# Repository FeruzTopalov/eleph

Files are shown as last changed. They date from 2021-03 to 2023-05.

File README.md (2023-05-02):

# **ELEPH** - _Never Get Lost!_

> **Note**
> Development of this device has been finished, only bug-fixes in the FW are possible
> There is an improved version of this device being under development, please see <https://github.com/FeruzTopalov/spoke>

<p align="center">
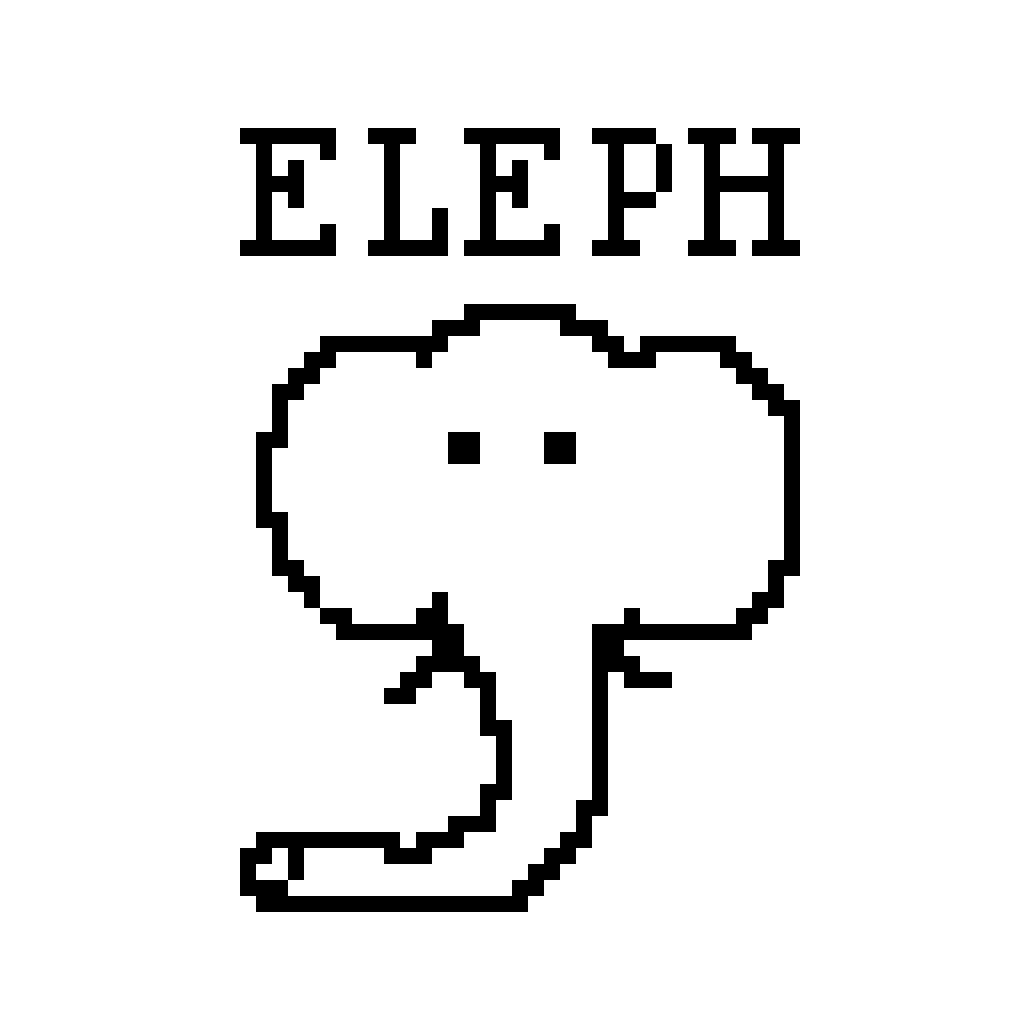
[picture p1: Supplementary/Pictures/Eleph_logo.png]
  
</p>

<p align="center">
  <i>Dedicated to my friend Alexander Sadaev, rock climber.</i>
</p>

Eleph is a GPS-based Local Relative Navigation System (LRNS) for group of up to 6 members. It allows you to share your positional data in **real-time** among other Eleph-devices and navigate to each of them in a relative manner by providing **Distance** and **Azimuth** information - like RADAR does.

## Demonstration

Before diving into the details, watch the demo on **YouTube**: <https://youtu.be/EMacKdg9Z_0>

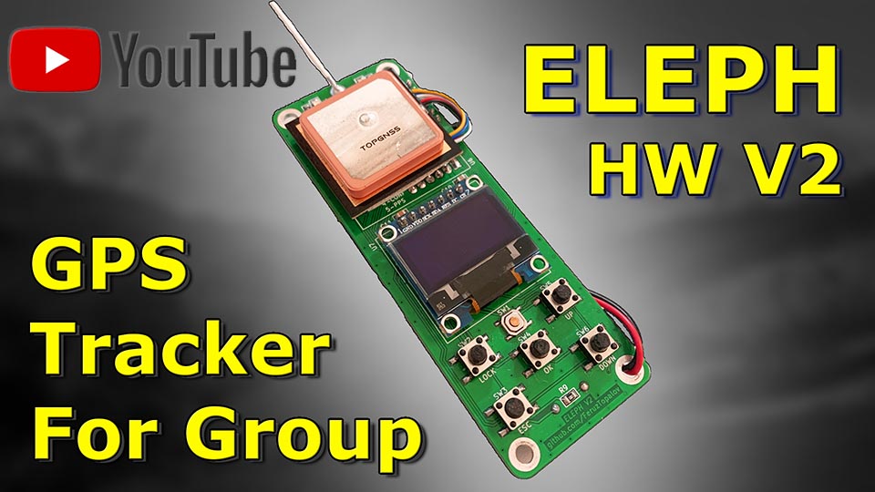
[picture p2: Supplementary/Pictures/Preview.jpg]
YouTube Video!


## Problem & Solution

As long as you stay under cell-coverage a navigation, either absolute or relative, is not a problem at all. You just use your phone with maps and messengers to find or share locations. Things change when you go off-grid. Hiking, skiing, sailing or whatever outdoor activity are a potential place to lose sight of your teammates. How to navigate in the group? Hopefully, there are couple of solutions available on the market:

* [LynQ](https://lynqme.com/pages/dev-consumer)
* [XQUAD](https://www.indiegogo.com/projects/xquad-smart-location-tracking-without-phones#/)
* [GoFindMe](https://www.indiegogo.com/projects/gofindme-a-gps-tracker-works-without-cell-service/#/)
* [GoTenna](https://gotennamesh.com/products/mesh)
* Also [GARMIN Dog collar](https://buy.garmin.com/en-US/US/c12522-p1.html)
* Also any [AIS](https://en.wikipedia.org/wiki/Automatic_identification_system) system

unfortunately all of them are commercial. But not the **Eleph**! 

**Eleph** is _open-source/open-hardware_ device which contains all major features needed for group navigation, such as:

* Detailed absolute positional information about each device in group
* RADAR-like interface with relative positional information about each device in group
* Memory slots to hold the position of any device and navigate it later
* GeoFence feature
* Timeout feature
* Alarm button

Due to open-source and simple and cheap hardware, Eleph is highly flexible solution that could be adapted to any use case you want:

* Hiking
* Climbing
* Sailing
* Hunting with the dogs
* Assets tracking
* and more...

## Technology

Eleph is written in pure C and runs on STM32 microcontroller. It has GPS module to receive positional data and synchronization signal, radio transceiver to exchange with radio packets between other devices, graphical display to show information on it, EEPROM memory IC to store coordinates, tactile buttons to control the device, buzzer to notify about events and couple of LEDs.

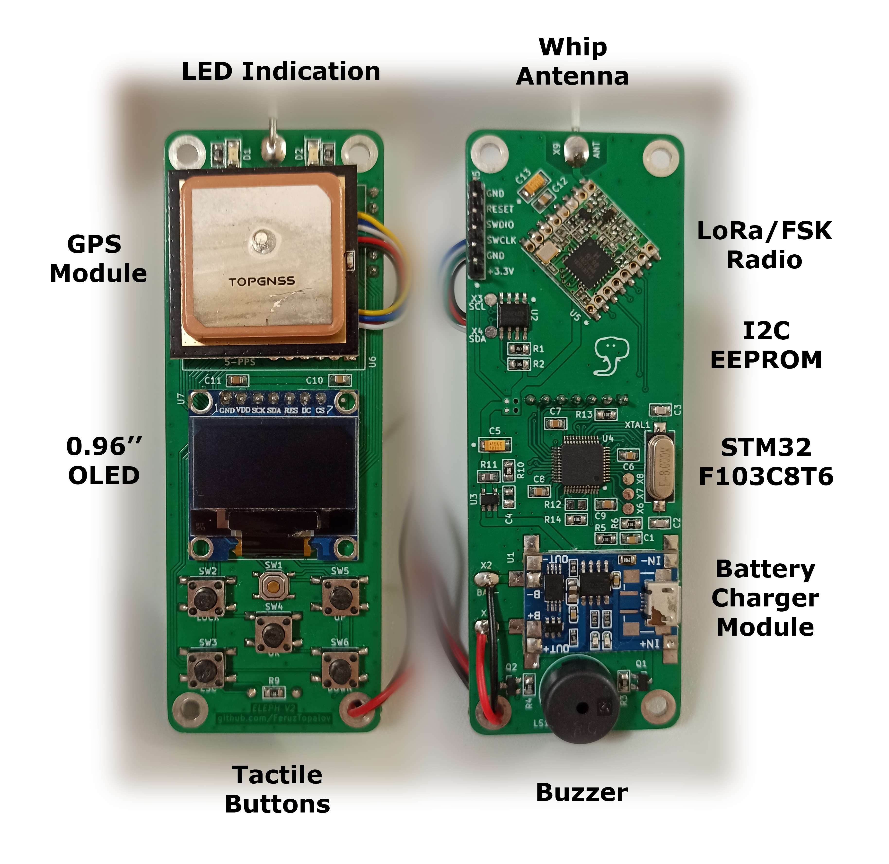
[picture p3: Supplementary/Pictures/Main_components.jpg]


GPS module provides NMEA-0183 stream at 9600 baud. Microcontroller process the stream using DMA and parse it. Fields being extracted are RMC, GGA, GSA, GSV. Those give us information about time, date, latitude, longitude, speed, course, altitude, satellites in view and in use, navigation mode and validness of data.

GPS module also provides time synchronization signal - PPS. It is used as a time reference for the transmitting and receiving radio packets inside a current group of devices. Each group operates at the specific frequency channel, the way like regular radios. Each device in a group has unique predefined number from 1 to 6, so there are 6 members in a group maximum. Eleph uses TDMA technique to give channel access for each group member, so the device number corresponds to the time-slot occupied by device. There are 125 ms timer which starts counting from the rise of the PPS pulse. First 125 ms time-slot is used to parse and prepare positional data of the device. Next six time-slots are used to exchange with the positional data between devices via radio. A device is in TX state when time-slot number is equal to the device number, and in RX state otherwise. Remaining time before next PPS is reserved for relative positions calculation and displaying the results.

Eleph uses FSK transceiver and operates in LPD 433 MHz band (please make sure you are allowed to use those frequencies in your region, change otherwise). Data rate is 2400 bps, deviation is 2400 Hz (mod index = 2), channel spacing is 25 kHz. Packet structure is shown below. It consist of 29 bytes total and takes ~97 ms to be transmitted over-the-air.

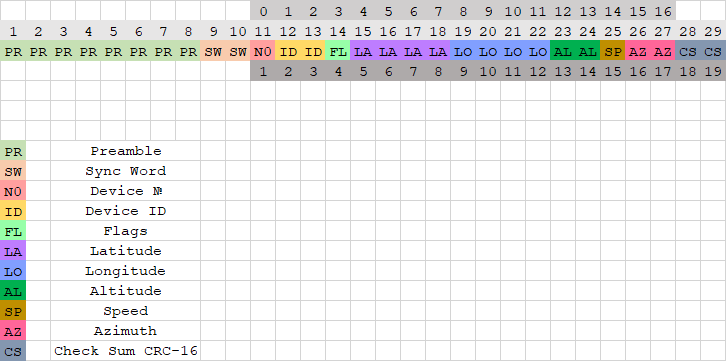
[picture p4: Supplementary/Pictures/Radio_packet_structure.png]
Packet structure


In order to calculate relative positions of other devices, Eleph uses two formulas. First one is [Haversine formula](https://en.wikipedia.org/wiki/Haversine_formula) which determines the distance between two points on a sphere. The second one is [Loxodrome formula](https://en.wikipedia.org/wiki/Rhumb_line) which determines bearing to a point on a sphere relative to true north. All calculations are performed with a highest possible, double precision, so the results are in a great agreement with my simulations on PC. Precision of the formulas is another matter. It is known that haversine formula is numerically better-conditioned for small distances, but on the other side it doesn't take into account ellipsoidness of the Earth and uses it's mean radius. Also it is known that loxodrome (or rhumb line) shows not-the-shortest way to reach point of interest (the shortest way is provided by orthodrome, or great circle route), but the constant bearing, which is more useful in practice. Anyway, my simulations using Google Earth Pro ruler leave me no concerns about accuracy of used formulas. According to them the error for both is less than 1% as long as the distance is smaller than 300 km (!).

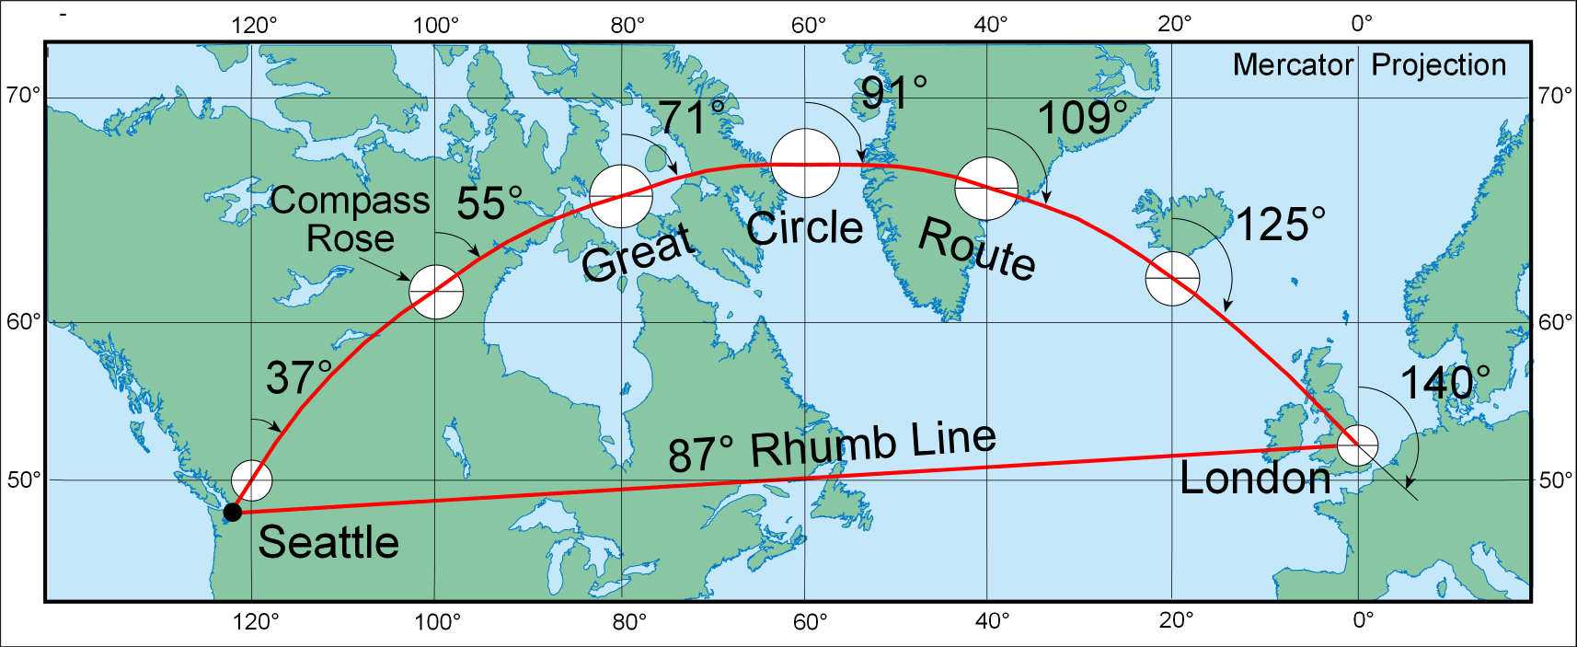
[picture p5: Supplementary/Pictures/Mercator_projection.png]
Mercator


<p align="center">
  <i>(courtesy of <a href="https://www.esri.com/arcgis-blog/products/product/mapping/mercators-500th-birthday/">ESRI</a>)</i>
</p>

---

## FAQ

* _**Why is it called Eleph?**_ -Eleph stands for elephant. Elephants are a social animals, they form close bonds and stay in-touch - that is the main aim of the Eleph device.
* _**Why no LoRa yet?**_ -Believe or not, but i see no reason to use LoRa in the Eleph right now. Mainly due to low data rate. Probably next time, when i shorten payload, i will switch to LoRa mode.
* _**Why there is no compass?**_ -When i started the project i thought that COG (Course over Ground) information from the GPS would be enough, and that the COG relates to the true north, while compass gives magnetic north. Obviously information about true north is more valuable. The drawback for now is that COG requires you to move, there is no way to find the direction standing still.
* _**Any plans to resume the project?**_ -Next milestone is to rework user interface, make it simpler; refuse from excessive payload information, leaving just Lat/Lon data; update schematic/hardware. 
* _**How can i support the project?**_ -Eleph really needs your support. Main functionality is tested, but full and comprehensive outdoor tests are nor performed well yet. You could build it, test it on your side and report an issue if so - that is the best way to support.

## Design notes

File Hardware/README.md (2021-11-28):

# Eleph Hardware
This folder contains hardware design of the ELEPH

## Design files
In the "**KiCad**" folder you can find KiCad project of the Eleph.

## Schematic
In the "**Schematic**" folder you can find PDF file with the schematic diagram.

## Production files
In the "**Gerbers**" folder you can find production files of Eleph.

## Hardware Notes
Couple of words about power supply. Supply chain is **_Single 18650 -> LDO 3.3V_**. I found no reason to put DC/DC because in common they have 80%-90% of efficiency, while LDO has ~78% in worst case (3.3V / 4.2V = 0.78). Do the increased complexity and cost worth several percent of efficiency? I do not think so.

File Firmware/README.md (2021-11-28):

# Eleph Firmware
This folder contains firmware of the ELEPH

## Source code
In the "**CubeIDE**" folder you can find project with the source code. As you can see it is created in CubeIDE and compiled using built-in **arm-none-eabi-gcc**.

The project is configured that way it should compile on your computer without problems. Follow the next steps:

* Open "**.project**" in [CubeIDE](https://www.st.com/en/development-tools/stm32cubeide.html) (tested on Version: 1.5.0)
* Current configuration should be **Debug**, otherwise "_Project -> Build Configurations -> Set Active -> Debug_"
* Clean current configuration "_Project -> Clean... -> Clean_"
* Build "_Project -> Build Project_"
* Enshure that you got "**Build Finished. 0 errors, 0 warnings.**" console message
* Flash the firmware directly from CubeIDE "_Run -> Run_", or use "**Eleph.hex**" or "**Eleph.bin**" from "_/CubeIDE/Debug_" folder to flash any of them using classic way via [ST-LINK Utility](https://www.st.com/en/development-tools/stsw-link004.html)

## Different frequency programming

Eleph uses [RFM98W](https://www.hoperf.com/modules/lora/RFM98.html) transceiver module which operates in LPD 433 band.

You are able to use any version of RFM module which operates in allowed band in your country. Original transceivers by Semtech could be supported too. 

To change base frequency you should make changes at least in "**rfm98_config.h**" file in "RFM_CONF_ARRAY" . Replacement of the module with another assumes changes in radio driver "**rfm98.c**".

Transceiver modules other than RFM98W are not tested.

## LCD images preparation

If you were curious enough, you may found that Eleph's "devices" and "radar" screens use predefined bitmap templates that appear on LCD before printing other strings. You could find them in _"/Supplementary/ScreenTemplates/"_ directory.

In case if you want to change those templates, you cold use:
* FastLCD (by Bojan I. - MICRODESIGN, v1.2.0) in order to change it (currently available here http://avrproject.ru/nokia3310/FastLCD.exe). Also any graphical editor could be used.
* Image Generate (by Alex_EXE, v2.104) in order to convert bitmap into HEX array (available here https://alex-exe.ru/programm/image-generate/).
* Also i recommend to use DotMatrixTool (http://dotmatrixtool.com/) to generate separate symbols.

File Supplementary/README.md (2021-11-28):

# Eleph Supplementary
This folder contains supplementary materials for the ELEPH:

* **Pictures** - graphical material for the front page
* **ScreenTemplates** - Template bitmaps for Eleph's menu (see _"/Firmware/README.md"_)

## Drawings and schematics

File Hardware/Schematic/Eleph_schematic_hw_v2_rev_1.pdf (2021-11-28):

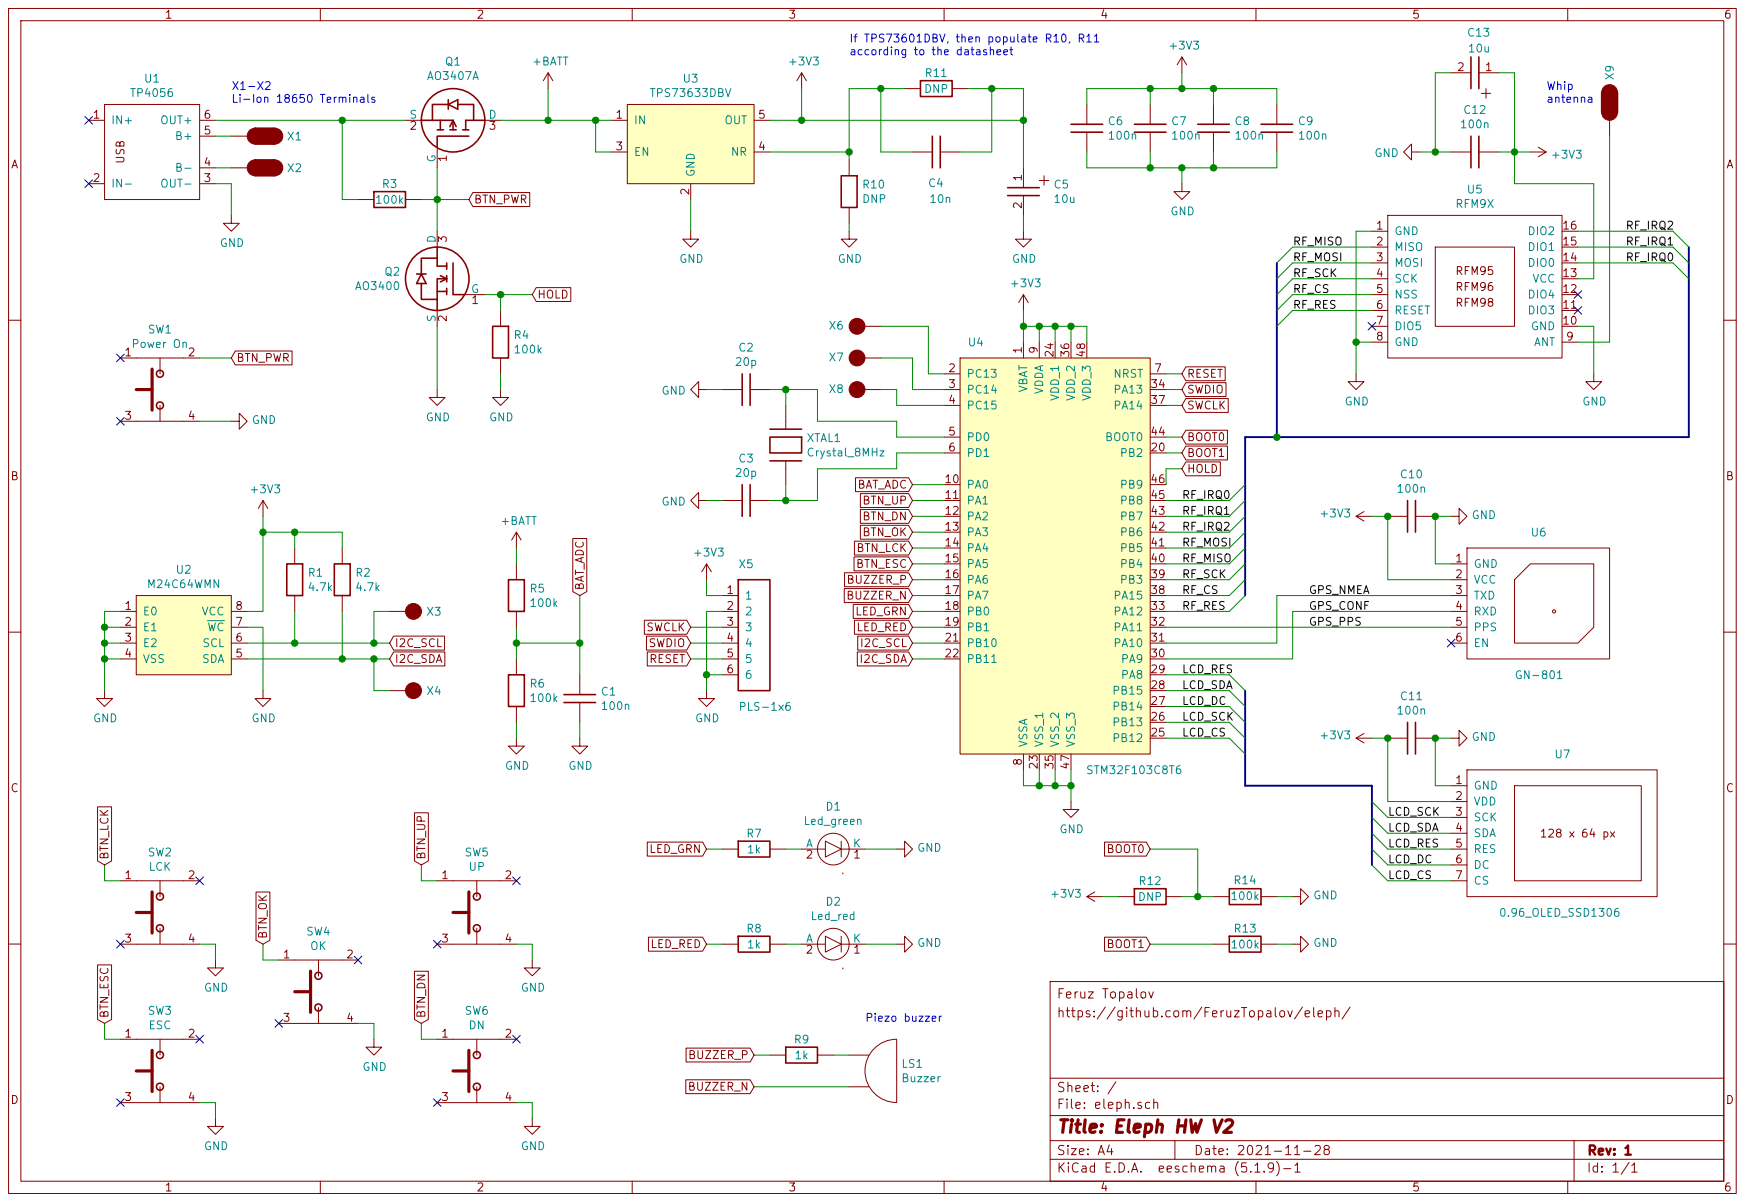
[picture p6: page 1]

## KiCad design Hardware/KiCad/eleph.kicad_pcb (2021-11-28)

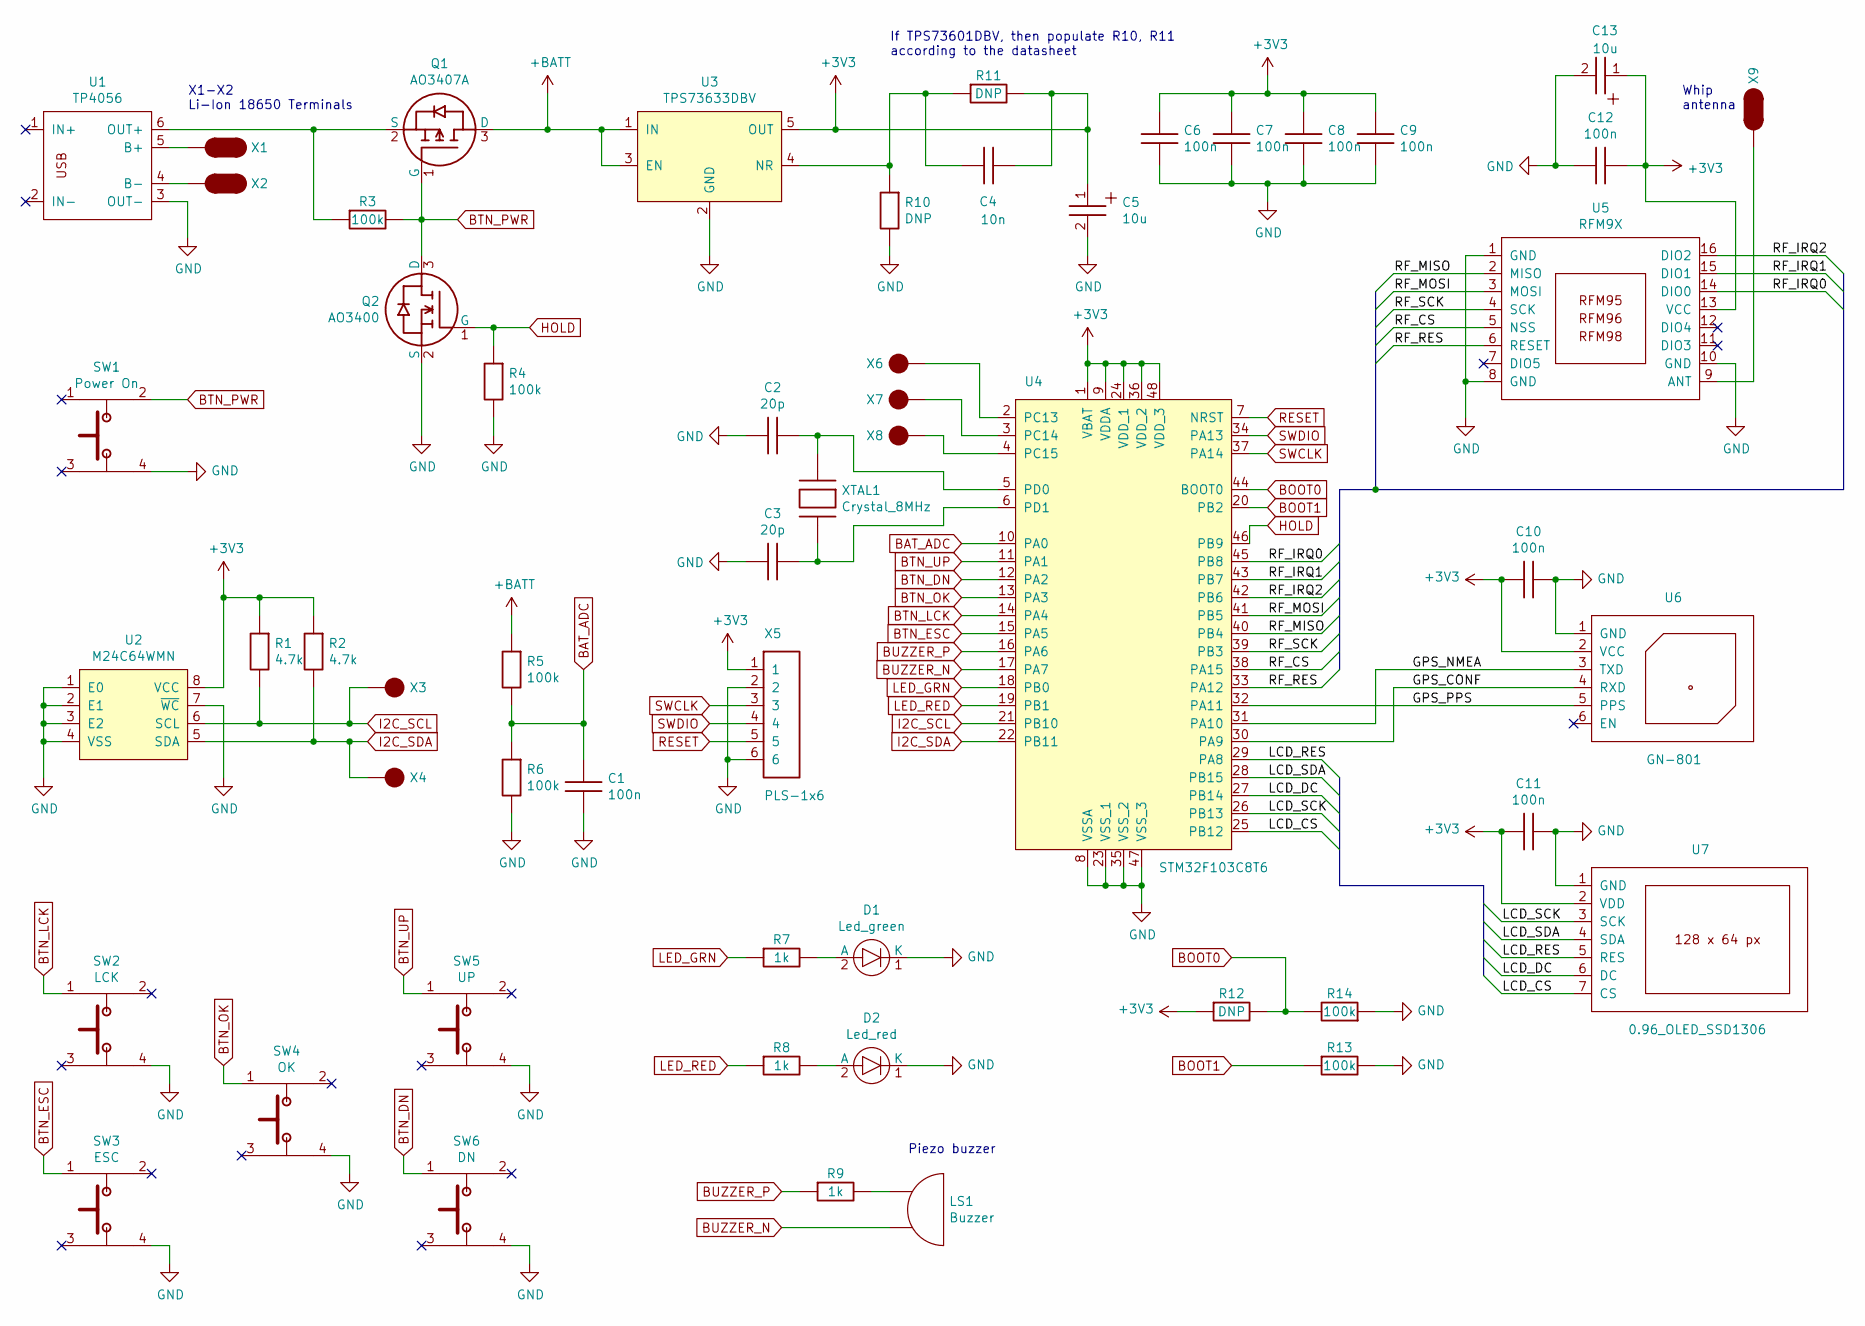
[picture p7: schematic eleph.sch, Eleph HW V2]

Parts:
C1, C6, C7, C8, C9, C10, C11, C12: 100n; C0805
C2, C3: 20p; C0805
C4: 10n; C0805
C5, C13: 10u; C_tantA
D1: Led_green; D1206
D2: Led_red; D1206
LS1: Buzzer; Buzzer_pitch7.6mm
Q1: AO3407A; SOT-23
Q2: AO3400; SOT-23
R1, R2: 4.7k; R0805
R3, R4, R5, R6, R13, R14: 100k; R0805
R7, R8, R9: 1k; R0805
R10, R11, R12: DNP; R0805
SW1: Power On; 52x52switch_smd_lowprofile
SW2: LCK; 6x6switch_smd
SW3: ESC; 6x6switch_smd
SW4: OK; 6x6switch_smd
SW5: UP; 6x6switch_smd
SW6: DN; 6x6switch_smd
U1: TP4056
U2: M24C64WMN; SOIC-8
U3: TPS73633DBV; SOT-23-5
U4: STM32F103C8T6; LQFP-48
U5: RFM9X
U6: GN-801
U7: 0.96_OLED_SSD1306; 0.96_OLED_SSD1306_7pin
X1, X2: Pad_oval
X3, X4, X6, X7, X8: Pad_round
X5: PLS-1x6; 1x6header
X9: Pad_oval; Antenna_terminal
XTAL1: Crystal_8MHz; HC49SM

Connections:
+3V3: C4.1, C5.1, C6.1, C7.1, C8.1, C9.1, C10.1, C11.1, C12.2, C13.1, R1.1, R2.1, R11.2, R12.1, U2.8 (VCC), U3.5 (OUT), U4.1 (VBAT), U4.9 (VDDA), U4.24 (VDD_1), U4.36 (VDD_2), U4.48 (VDD_3), U5.13 (VCC), U6.2 (VCC), U7.2 (VDD), X5.1
+BATT: Q1.3 (D), R5.1, U3.1 (IN), U3.3 (EN)
/GPS_CONF: U4.30 (PA9), U6.4 (RXD)
/GPS_NMEA: U4.31 (PA10), U6.3 (TXD)
/GPS_PPS: U4.32 (PA11), U6.5 (PPS)
/LCD_CS: U4.25 (PB12), U7.7 (CS)
/LCD_DC: U4.27 (PB14), U7.6 (DC)
/LCD_RES: U4.29 (PA8), U7.5 (RES)
/LCD_SCK: U4.26 (PB13), U7.3 (SCK)
/LCD_SDA: U4.28 (PB15), U7.4 (SDA)
/RF_CS: U4.38 (PA15), U5.5 (NSS)
/RF_IRQ0: U4.45 (PB8), U5.14 (DIO0)
/RF_IRQ1: U4.43 (PB7), U5.15 (DIO1)
/RF_IRQ2: U4.42 (PB6), U5.16 (DIO2)
/RF_MISO: U4.40 (PB4), U5.2 (MISO)
/RF_MOSI: U4.41 (PB5), U5.3 (MOSI)
/RF_RES: U4.33 (PA12), U5.6 (RESET)
/RF_SCK: U4.39 (PB3), U5.4 (SCK)
BAT_ADC: C1.1, R5.2, R6.1, U4.10 (PA0)
BOOT0: R12.2, R14.2, U4.44 (BOOT0)
BOOT1: R13.1, U4.20 (PB2)
BTN_DN: SW6.1, U4.12 (PA2)
BTN_ESC: SW3.1, U4.15 (PA5)
BTN_LCK: SW2.1, U4.14 (PA4)
BTN_OK: SW4.1, U4.13 (PA3)
BTN_PWR: Q1.1 (G), Q2.3 (D), R3.2, SW1.2
BTN_UP: SW5.1, U4.11 (PA1)
BUZZER_N: LS1.2, U4.17 (PA7)
BUZZER_P: R9.1, U4.16 (PA6)
GND: C1.2, C2.1, C3.1, C5.2, C6.2, C7.2, C8.2, C9.2, C10.2, C11.2, C12.1, C13.2, D1.1 (K), D2.1 (K), Q2.2 (S), R4.2, R6.2, R10.2, R13.2, R14.1, SW1.4, SW2.4, SW3.4, SW4.4, SW5.4, SW6.4, U1.3 (OUT-), U2.1 (E0), U2.2 (E1), U2.3 (E2), U2.4 (VSS), U2.7 (~WC), U3.2 (GND), U4.8 (VSSA), U4.23 (VSS_1), U4.35 (VSS_2), U4.47 (VSS_3), U5.1 (GND), U5.8 (GND), U5.10 (GND), U6.1 (GND), U7.1 (GND), X5.2, X5.6
HOLD: Q2.1 (G), R4.1, U4.46 (PB9)
I2C_SCL: R1.2, U2.6 (SCL), U4.21 (PB10), X3.1
I2C_SDA: R2.2, U2.5 (SDA), U4.22 (PB11), X4.1
LED_GRN: R7.1, U4.18 (PB0)
LED_RED: R8.1, U4.19 (PB1)
unnamed: C2.2, U4.5 (PD0), XTAL1.1
unnamed: C3.2, U4.6 (PD1), XTAL1.2
unnamed: C4.2, R10.1, R11.1, U3.4 (NR)
unnamed: D1.2 (A), R7.2
unnamed: D2.2 (A), R8.2
unnamed: LS1.1, R9.2
unnamed: Q1.2 (S), R3.1, U1.6 (OUT+)
unnamed: U1.4 (B-), X2.1
unnamed: U1.5 (B+), X1.1
unnamed: U4.2 (PC13), X6.1
unnamed: U4.3 (PC14), X7.1
unnamed: U4.4 (PC15), X8.1
unnamed: U5.9 (ANT), X9.1
RESET: U4.7 (NRST), X5.5
SWCLK: U4.37 (PA14), X5.3
SWDIO: U4.34 (PA13), X5.4

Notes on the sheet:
X1-X2 Li-Ion 18650 Terminals
If TPS73601DBV, then populate R10, R11 according to the datasheet
Whip antenna
Piezo buzzer

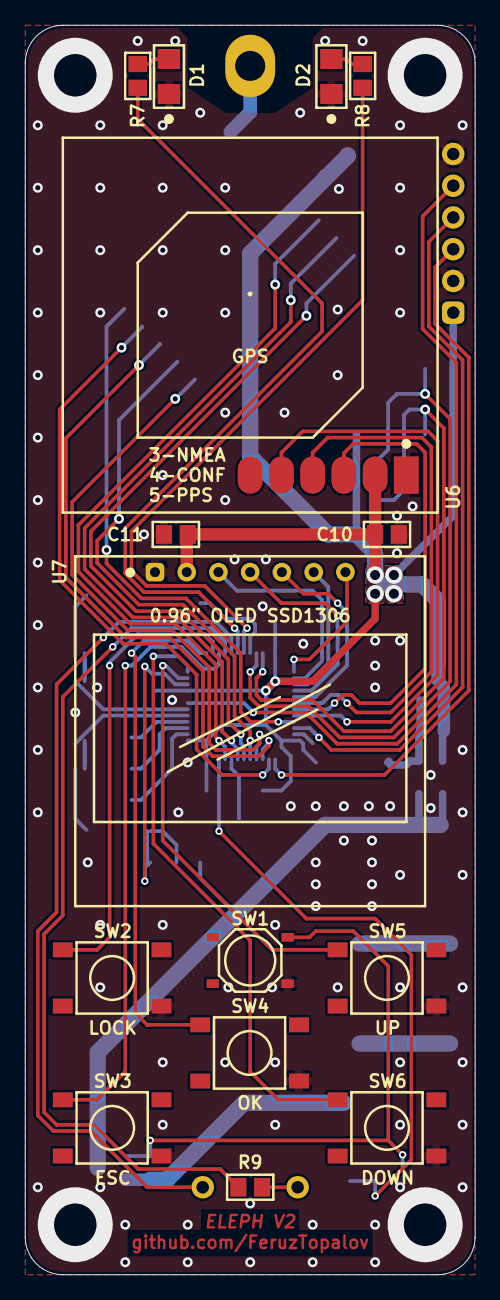
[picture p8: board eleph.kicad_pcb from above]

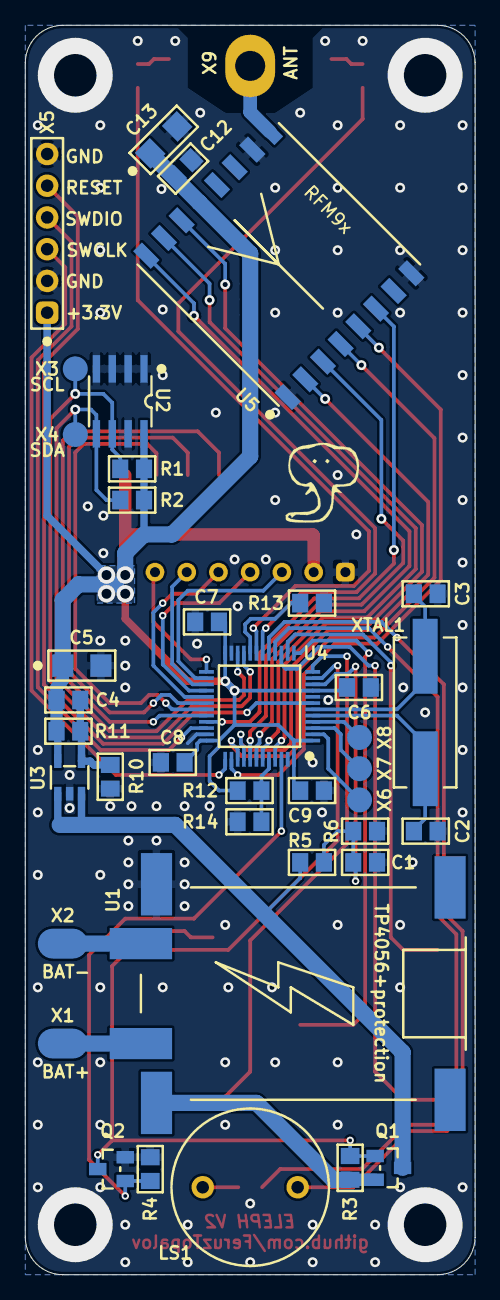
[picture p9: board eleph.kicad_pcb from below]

Board: 2 copper layers, 36.0 x 100.0 mm, 55 parts (40 on the bottom side), 51 nets.

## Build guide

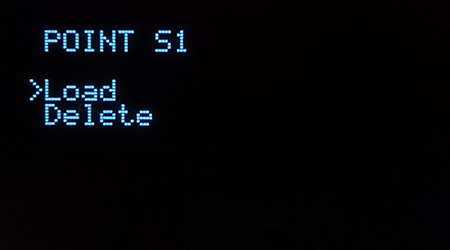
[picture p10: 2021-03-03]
Supplementary/Pictures/UserManual/PointOptions.png

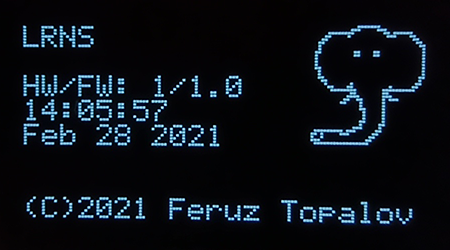
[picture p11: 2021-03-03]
Supplementary/Pictures/UserManual/Info.png

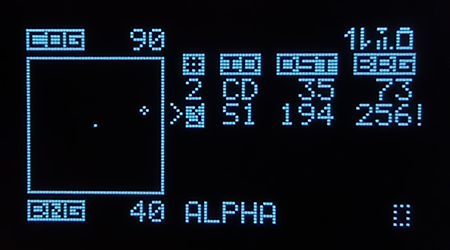
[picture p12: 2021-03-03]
Supplementary/Pictures/UserManual/RadarHide2.png

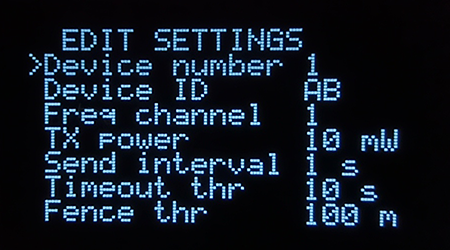
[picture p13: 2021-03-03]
Supplementary/Pictures/UserManual/EditSettings.png

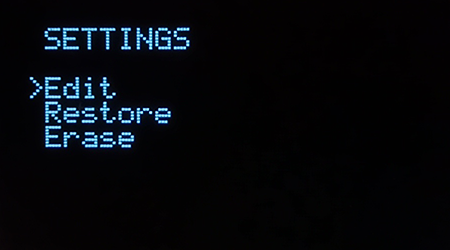
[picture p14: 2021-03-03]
Supplementary/Pictures/UserManual/Settings.png

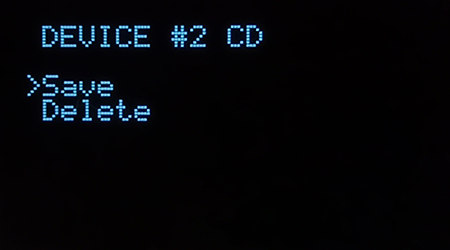
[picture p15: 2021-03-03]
Supplementary/Pictures/UserManual/EachDeviceOptions.png

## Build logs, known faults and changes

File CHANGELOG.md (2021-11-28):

# Eleph changelog
**Legend:** _"Hardware version/Software version"_  

---
#### v2/1.0 - November 28, 2021
- New hardware
- PCB files ready to production
- Updated UI
- Many bugs fixed

---
#### v1/2.0 - April 10, 2021
- Lower Fclk down to 24 MHz
- Put MCU in a sleep when idle
- Add screen on/off function via PWR button
- Disable peripheral while unused
- Make buttons scan on timer interrupts, optimize routine
- Make ADC reading on interrupts
- Switch 1 second counter from SysTick to RTC with LSI
- Replace beep gating timer
- Update occurrences of the beep
- Fix I2C stop condition bug
- Update green led behavior
- Add include guards to the *.h files
- Add bit banding support
- A lot of minor improvements

---
#### v1/1.0 - February 14, 2021
- Initial release

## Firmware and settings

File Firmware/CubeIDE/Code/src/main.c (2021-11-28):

/*
    ELEPH - Local Relative Navigation System <https://github.com/FeruzTopalov/eleph/>

	Copyright (C) 2021 Feruz Topalov
	Released under the GNU General Public License v3.0 <https://www.gnu.org/licenses/>
    
    file: main.c
*/



#include <string.h>
#include "stm32f10x.h"
#include "main.h"
#include "gpio.h"
#include "spi.h"
#include "ssd1306.h"
#include "service.h"
#include "uart.h"
#include "gps.h"
#include "rfm98.h"
#include "timer.h"
#include "i2c.h"
#include "m24c64.h"
#include "settings.h"
#include "buttons.h"
#include "menu.h"
#include "adc.h"
#include "points.h"
#include "lrns.h"
#include "ssd1306_bitmaps.h"
#include "rfm98_config.h"



void setup_interrupt_priorities(void);



//TIMERS
uint32_t uptime = 0;
uint32_t pps_counter = 0;
uint8_t overflow_counter = 0;
uint8_t time_slot = 0;



//MAIN
struct main_flags_struct main_flags = {0};
struct settings_struct *p_settings;
struct gps_num_struct *p_gps_num;
uint8_t *p_send_interval_values;
uint8_t current_radio_status = 0;

char buff[21];

//PROGRAM
int main(void)
{
    gpio_init();
    hold_power();
    timers_init();
    spi1_init();
    spi2_init();
    i2c_init();
    uart_dma_init();
    settings_load();
    ssd1306_init();
    rfm98_init();
    ext_int_init();
    adc_init();
    adc_start_bat_voltage_reading();
    init_lrns();
    init_menu();
    init_points();

    p_settings = get_settings();
    p_gps_num = get_gps_num();
    p_send_interval_values = get_send_interval_values();

    ssd1306_bitmap(&startup_screen[0]);
    ssd1306_update();
    delay_cyc(200000);
    draw_current_menu();

    setup_interrupt_priorities();
    __enable_irq();
    make_a_beep();
    gps_init();


    while (1)
    {

    	//Scan Keys
    	if (main_flags.begin_scan_buttons == 1)
    	{
    		main_flags.begin_scan_buttons = 0;
    		change_menu(scan_buttons());
    	}



        //Parse GPS after PPS interrupt or UART DMA overflow
        if (main_flags.nmea_ready == 1)
        {
            main_flags.nmea_ready = 0;

            if (parse_gps() == 1)
            {
            	main_flags.do_screen_update = 1; //show results after successful parsing

				if (get_gps_status() == GPS_DATA_VALID)
				{
					main_flags.gps_valid = 1;

					if 	((main_flags.pps_exist == 1) &&
						((p_gps_num->second % p_send_interval_values[p_settings->send_interval_opt]) == 0)) //ready to txrx when pps exist and current second divides by send interval without remainder
					{
						gps_air_update_my_data(uptime);
						fill_air_packet_with_struct_data();
						main_flags.txrx_ready = 1;
					}
					else
					{
						main_flags.txrx_ready = 0;
					}
				}
				else
				{
					main_flags.gps_valid = 0;
				}
            }
        }





        //Process the radio interrupt
        if (main_flags.rx_packet_ready == 1)
        {
        	main_flags.rx_packet_ready = 0;

            current_radio_status = rfm98_get_irq_status();

            if (current_radio_status & RF_IRQFLAGS2_CRCOK)	//if CRC is ok
            {
            	rfm98_get_rx_packet();
            	fill_struct_with_air_packet_data(uptime);   //parse air data from another device (which has ended TX in the current time_slot)
            	led_green_on();
            }
            else if (current_radio_status & RF_IRQFLAGS2_PAYLOADREADY)	//if CRC is wrong but packet has been received
            {
            	rfm98_flush_fifo();
            }
        }



        //After each second
        if (main_flags.tick_1s == 1)
        {
        	main_flags.tick_1s = 0;
            adc_check_bat_voltage();
            calc_timeout(uptime);
        }


        
        //Checks after receiving packets from all devices or after no txrx; performing beep
        if (main_flags.time_slots_end == 1)
        {
        	main_flags.time_slots_end = 0;

        	process_all_devices();

        	uint8_t alarm_status = 0;
        	alarm_status += check_alarms();
        	alarm_status += check_timeout();	//check timeout flags and get the result only after the end of the TRX sequence
        	alarm_status += check_fence();

        	if (main_flags.battery_low == 1)	//when GPS is good and we are in the active state then check battery here
        	{
        		alarm_status += main_flags.battery_low;
        		main_flags.battery_low = 0;
        	}

        	if (alarm_status > 0)
        	{
        		main_flags.do_beep = 1;
        	}

        	main_flags.do_screen_update = 1;
        }
        else if ((main_flags.battery_low == 1) && (main_flags.pps_exist == 0)) 		//Check battery here when no GPS PPS (once in GET_BAT_VOLTAGE_INTERVAL)
        {
        	main_flags.battery_low = 0;
        	main_flags.do_beep = 1;
        }



        //Make some noise
        if (main_flags.do_beep == 1)
        {
        	main_flags.do_beep = 0;
        	make_a_beep();
        }



        //Finally update screen
        if (main_flags.do_screen_update == 1)
        {
        	main_flags.do_screen_update = 0;
        	draw_current_menu();
        }



    //Wait for interrupt
    __WFI();

    }
}



//DMA UART RX overflow
void DMA1_Channel5_IRQHandler(void)
{
    DMA1->IFCR = DMA_IFCR_CGIF5;     //clear all interrupt flags for DMA channel 5
    
    uart_dma_stop();
    backup_and_clear_uart_buffer();
    uart_dma_restart();

    if (main_flags.pps_exist == 1) 	//if last pps status was "sync" then make a beep because we lost PPS
    {
    	make_a_long_beep();			//make a long beep
    }

    pps_counter = 0;
    main_flags.pps_exist = 0;
    main_flags.nmea_ready = 1;
}



//GPS PPS interrupt
void EXTI15_10_IRQHandler(void)
{
	EXTI->PR = EXTI_PR_PR11;        //clear interrupt
	timer1_start();                 //the first thing to do is to start time slot timer right after PPS

	uart_dma_stop();				//fix the data
	backup_and_clear_uart_buffer();
	uart_dma_restart();

	pps_counter++;

	if (pps_counter > 2) //skip first two pps impulses: skip first PPS, ignore previous nmea data; skip second PPS, but fix the nmea data acquired after first PPS
	{
		main_flags.pps_exist = 1;
		main_flags.nmea_ready = 1;
	}
}



//RFM98 interrupt (PayloadReady or PacketSent)
void EXTI9_5_IRQHandler(void)
{
    EXTI->PR = EXTI_PR_PR8;         //clear interrupt

    if (main_flags.tx_state == 1)
    {
    	main_flags.tx_state = 0;
    	led_green_on();
    }
    else
    {
    	main_flags.rx_packet_ready = 1;
    }

}



//Time slot interrupt
void TIM1_UP_IRQHandler(void)
{
    TIM1->SR &= ~TIM_SR_UIF;                    //clear interrupt
    led_green_off();
    
    overflow_counter++;             			//increment ovf counter

    
    if (main_flags.txrx_ready == 1)
    {
		if (overflow_counter == (p_settings->devices_on_air + 1)) //end of the last time slot
		{
			timer1_stop_reload();
			overflow_counter = 0;
			main_flags.txrx_ready = 0;
			main_flags.time_slots_end = 1;
		}
		else
		{
			time_slot = overflow_counter;

			if (time_slot == p_settings->device_number)
			{
				if (rfm98_tx_packet())
				{
					main_flags.tx_state = 1;
				}
			}
			else
			{
				rfm98_start_rx();
			}
		}
    }
    else
    {
		timer1_stop_reload();
		overflow_counter = 0;

    	if (main_flags.gps_valid == 1)
    	{
    		main_flags.time_slots_end = 1; //if gps is valid then calculate rel pos for all devices
    	}
    	else
    	{
    		main_flags.time_slots_end = 0;
    	}
    }
}



//End of beep
void SysTick_Handler(void)
{
	timer3_stop();	//pwm
	timer3_clock_disable();
	systick_stop();	//gating
}



//Uptime counter (every 1 second)
void RTC_IRQHandler(void)
{
	RTC->CRL &= ~RTC_CRL_SECF;		//Clear interrupt

    uptime++;
    main_flags.tick_1s = 1;
}



//End of ADC conversion (battery voltage)
void ADC1_2_IRQHandler(void)
{
	main_flags.battery_low = adc_read_bat_voltage_result(); 			//EOC is cleared automatically after ADC_DR reading
}



//Scan buttons interval
void TIM2_IRQHandler(void)
{
	TIM2->SR &= ~TIM_SR_UIF;        //clear gating timer int
	main_flags.begin_scan_buttons = 1;
}



void setup_interrupt_priorities(void)
{

#define GROUPS_8_SUBGROUPS_2	(4)

	NVIC_SetPriorityGrouping(GROUPS_8_SUBGROUPS_2);
	NVIC_SetPriority(EXTI15_10_IRQn, 	NVIC_EncodePriority(GROUPS_8_SUBGROUPS_2, 0, 0));		//PPS
	NVIC_SetPriority(TIM1_UP_IRQn, 		NVIC_EncodePriority(GROUPS_8_SUBGROUPS_2, 1, 0));		//Time slot
	NVIC_SetPriority(EXTI9_5_IRQn, 		NVIC_EncodePriority(GROUPS_8_SUBGROUPS_2, 2, 0));		//Radio
	NVIC_SetPriority(DMA1_Channel5_IRQn,NVIC_EncodePriority(GROUPS_8_SUBGROUPS_2, 3, 0));		//UART DMA
	NVIC_SetPriority(TIM2_IRQn, 		NVIC_EncodePriority(GROUPS_8_SUBGROUPS_2, 4, 0));		//Key scan
	NVIC_SetPriority(RTC_IRQn, 			NVIC_EncodePriority(GROUPS_8_SUBGROUPS_2, 5, 0));		//Uptime counter
	NVIC_SetPriority(ADC1_2_IRQn, 		NVIC_EncodePriority(GROUPS_8_SUBGROUPS_2, 6, 0));		//Battery voltage
	NVIC_SetPriority(SysTick_IRQn, 		NVIC_EncodePriority(GROUPS_8_SUBGROUPS_2, 7, 0));		//Beep end
}



uint32_t get_uptime(void)
{
	return uptime;
}



struct main_flags_struct *get_main_flags(void)
{
	return &main_flags;
}

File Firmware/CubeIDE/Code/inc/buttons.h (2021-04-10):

/*
    ELEPH - Local Relative Navigation System <https://github.com/FeruzTopalov/eleph/>

	Copyright (C) 2021 Feruz Topalov
	Released under the GNU General Public License v3.0 <https://www.gnu.org/licenses/>
    
    file: buttons.h
*/



#ifndef BUTTONS_HEADER
#define BUTTONS_HEADER



#define BTN_NO_ACTION        (0)

#define BTN_UP               (1)     //PA1
#define BTN_UP_LONG          (2)

#define BTN_DOWN             (3)     //PA2
#define BTN_DOWN_LONG        (4)

#define BTN_OK               (5)     //PA3
#define BTN_OK_LONG          (6)

#define BTN_PWR              (7)     //PA4
#define BTN_PWR_LONG         (8)

#define BTN_ESC              (9)     //PA5
#define BTN_ESC_LONG         (10)



uint8_t scan_buttons(void);



#endif /*BUTTONS_HEADER*/

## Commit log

2021-02-17 Add schematic, hardware readme, hardware pictures
2021-04-10 Fix schematic diagram, add missed pull-ups at SDA, SCK pins
2021-11-28 Upload KiCad project, source code, updated README files
    [eleph.kicad_pcb, eleph.sch]
